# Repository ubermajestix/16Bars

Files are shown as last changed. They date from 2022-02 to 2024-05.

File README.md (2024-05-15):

# 16Bars


16barsPCB

16Bars is a utility module designed to display how many 
measures have elapsed on a seven segment display given a clock pulse. 
The module resets every 8 or 16 measures (bars) or when the reset button is pressed.

This is my first module design and I've made several simplifying design choices:
1. A 1U version would be much more convienient
2. Reset jack would be nice to play better with midi or modules that output reset
3. Midi support? Accept MIDI TRS input for start, stop, and reset?
4. LFO output with LFO reset, could use 1st bar, n/2 bars, and last bar to self patch musical phrased LFO
## Rev 3.2 Updates and Issues

## Rev 2.0 Updates and Issues
I was successfully able to get JLCPCB to manufacture and place a lot of SMD components as I don't have the time or gear to get into surface mount, win! 

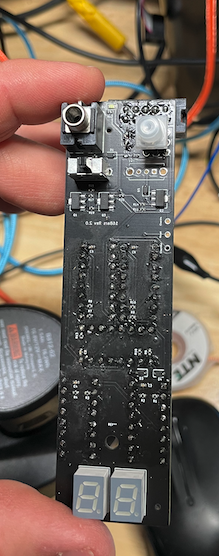
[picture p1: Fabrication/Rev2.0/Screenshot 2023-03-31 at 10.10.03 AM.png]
front of 2.0

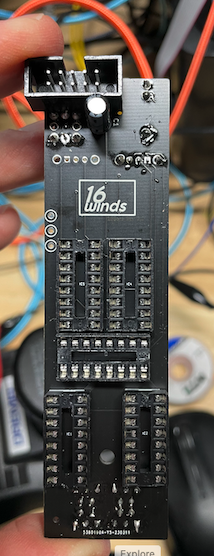
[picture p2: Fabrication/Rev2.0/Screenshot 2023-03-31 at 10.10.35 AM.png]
back of 2.0


I also breadboarded out and build test PCBS to validate significant portion of the Rev 2.0 design:
- Reset button uses a transistor to send a reset signal instead of directly sending +12v when pressed
- Two transistors to normalize a wide variety of incoming clock signal voltages and send +12v pulses to trigger the three counter ICs and blink the led in the reset button 
- 8 bar reset logic confirmed, 16 bar reset logic didn't work because I was rushing to get Rev 2.0 board to production.
- Built a switch test PCB. I ordered 4 different switches and after getting incorrect footprints for the seven segment leds from Mouser I didn't trust the switch footprints. I also wanted to validate the switch weight, height, footprint size tradeoffs, validate the switches are in-fact on-on SPDT, and ensure the switches are too able to be flipped by accident when patching as they control the reset logic and time signature (4/4 and 8/4). 

Issues
- The [surface mount transistors](https://www.lcsc.com/product-detail/Bipolar-Transistors-BJT_Jiangsu-Changjing-Electronics-Technology-Co-Ltd-C9634_C9634.html) do not work as intended. I am considering replacing them with through-hole NPN's I'm using on the breadboard to validate it's either a component problem or PCB routing problem. 

# Panel Design
Panel design ideas, PCB, and logo are in Panel/. I'm aiming for a wind theme throughout the design and naming.

Rev 2.0 panel design is coming along:

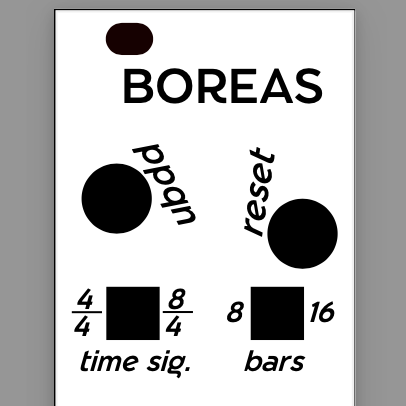
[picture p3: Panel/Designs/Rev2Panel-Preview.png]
panel preview


# LED Sheild Practice aka Clock Blink
The design and fabrication process can be intimidating for a beginner. What I've learned from
software development is to start easy and get something small all the way to production before tackling bigger
projects. 

I followed [Contextual Electronic's _Getting To Blinky 5.0](https://www.youtube.com/watch?v=BVhWh3AsXQs)_ to learn
KiCAD schematic design, PCB layout and design, and fabrication on a simple circuit.

I wanted to use a keyed power header, know it worked by lighting up an LED, and take a clock pulse in through a jack to light up an led.

I fabricated the boards and got the power led to light up from my Eurorack case! The blinking feature isn't working and
I'm debugging it as of March 2022. 

# Practice Panel
I also wanted to practice making a panel. Again, to simplify, I wanted to get the mounting holes placed correctly with oval
holes like Intellijel 1U modules b/c my rails are never exactly aligned top to bottom. I was planning to make a control panel for the
the ClockBlink board but I figured why not make a blank 1U panel with some Fiverr artwork? 

The blank panels turned out great, I fabbed them with OshPark.com in purple (their default) and black (After Dark). The holes
line up and they were $7 and $12 shipped for three copies.

sheep1u

# License
[Attribution 4.0 International (CC BY 4.0)](https://creativecommons.org/licenses/by/4.0/)

Open-source-hardware-logo

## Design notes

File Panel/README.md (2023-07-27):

# 16 Bars Panel

## Inspiration
16Winds name was inspired by a joke my wife and I made years ago when
I was doing side work to pay for our honeymoon. I would start my side
gig at 5:30am, work until my real job started at 8:30am, work a full
day, hit the gym around 5:30pm, cook dinner, hang out, enjoy some music
hobby time, relax together, and maybe knock out a few todo items. Late
into the evening we would joke we were on our 16th wind, instead of just 
a second wind, to get everything done in a day. 

When I started thinking about making synth modules I thought the name was
fitting as our lives have only gotten more busy with kids and work. The
time I'm able to spend working on this has drastically reduced and I really
feel like I'm on a 16th wind to get the energy to figure out electronics,
pcb design, panel design, manufacturing, part selection, branding and everything
else.

So 16Winds, how about naming the modules after the names given to the compass winds
(Borreas, Zephyrus, etc) thoughout antiquity, or maybe use the names of local winds (chinook, mistral, etc). 

## How To Get Artwork On The Panel
1. Design in InkScape
4. Use Svg2Shenzhen to setup layers
6. Resize artwork and place in layers (Svg2Shenzhen resizes the artboard, maybe I'm doing something wrong?)
7. Export to Kicad in a Footprints/ directory local to the project
8. Add local Footprints/ as a "Project Specific Library" in KiCad's Footprint Library Manager
9. Place footprints from new library.

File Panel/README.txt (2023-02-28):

# 16 Bars Panel

## Inspiration
16winds name was inspired by a joke my wife and I made years ago when
I was doing side work to pay for our honeymoon. I would start my side
gig at 5:30am, work until my real job started at 8:30am, work a full
day, hit the gym around 5:30pm, cook dinner, hang out, enjoy some music
hobby time, relax together, and maybe knock out a few todo items. Late
into the evening we would joke we were on our 16th wind, instead of just 
a second wind, to get everything done we wanted to in a day. 

When I started thinking about making synth modules I thought the name was
fitting as our lives have only gotten more busy with kids and work. The
time I'm able to spend working on this has drastically reduced and I really
feel like I'm on a 16th wind to get the energy need to figure out electronics,
pcb design, panel design, manufacturing, part selection, branding and everything
else.

So 16 winds, how about naming the modules after the names given to the compass winds
(Borreas, Zephyrus, etc) thoughout antiquity, or maybe use the names of local winds (chinook, mistral, etc). 

## How To Get Artwork On The Panel
1. Design in AffintyDesign
2. Export to SVG
3. Import to InkScape
4. Use Svg2Shenzhen to setup layers
6. Resize artwork and place in layers (Svg2Shenzhen resizes the artboard, maybe I'm doing something wrong?)
7. Export to Kicad in a Footprints/ directory local to the project
8. Add local Footprints/ as a "Project Specific Library" in KiCad's Footprint Library Manager
9. Place footprints from new library.

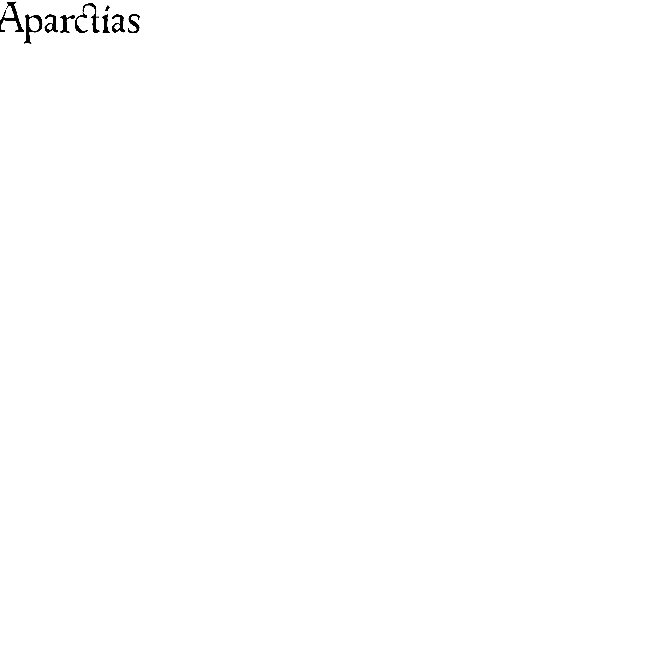
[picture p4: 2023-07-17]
Panel/Footprints/.svg2shenzhen-cache/images/F.SilkS_g187.png

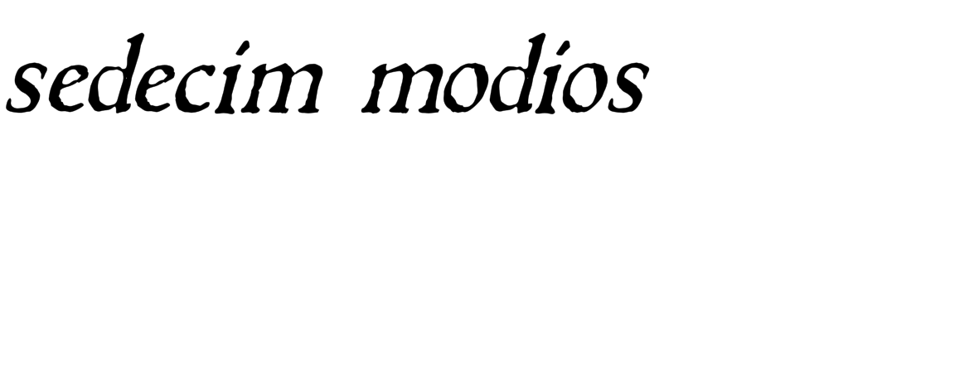
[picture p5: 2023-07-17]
Panel/Footprints/.svg2shenzhen-cache/images/F.Cu_g155.png

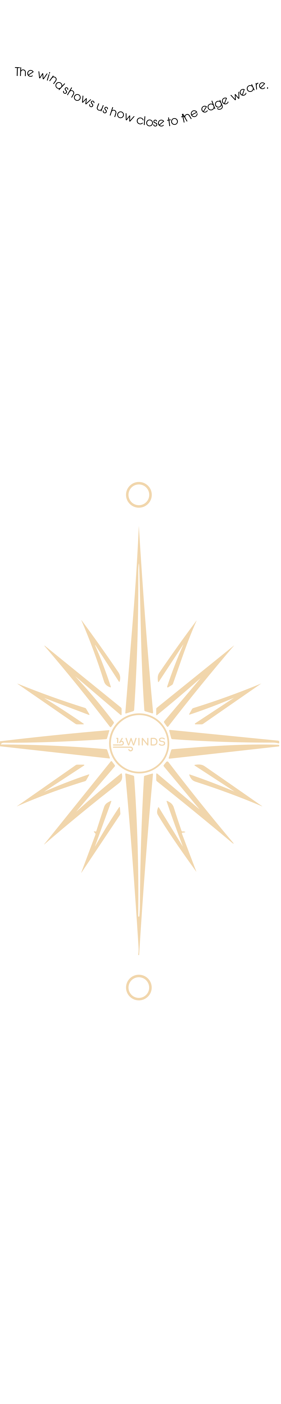
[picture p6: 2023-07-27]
Panel/Footprints/.svg2shenzhen-cache/images/B.Cu_g4975.png

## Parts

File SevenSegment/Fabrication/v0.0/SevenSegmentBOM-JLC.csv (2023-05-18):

Id | Designator | Footprint | Comment | LCSC Part Number
3 | R4,R3,R2,R1 | R_0402_1005Metric | 10K | C25744
5 | C2,C1 | C_0402_1005Metric | 100nf | C1525

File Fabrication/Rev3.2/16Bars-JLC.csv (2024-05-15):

Comment | Designator | Footprint | LCSC Part Number
330pf Unpolarized capacitor, small symbol | C11, | Capacitor_SMD:C_0402_1005Metric | C13533
LED Light emitting diode | D2, | LED_SMD:LED_0603_1608Metric | C2290
1N5819WS Diode | D5, D6, D7, D8, D9, | Diode_SMD:D_SOD-323 | C191023
470 Resistor | R1, R2, R3, R5, | Resistor_SMD:R_0402_1005Metric | C25117
1K Resistor | R4, R6, R7, R15, | Resistor_SMD:R_0402_1005Metric | C4410
10K Resistor | R12, | Resistor_SMD:R_0402_1005Metric | C4109

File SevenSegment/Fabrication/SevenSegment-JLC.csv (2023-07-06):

Comment | Designator | Footprint | LCSC Part Number
100nf Unpolarized capacitor | C1, C2, | Capacitor_SMD:C_0402_1005Metric | C1525
10K Resistor | R1, R2, R3, R4, | Resistor_SMD:R_0402_1005Metric | C25744

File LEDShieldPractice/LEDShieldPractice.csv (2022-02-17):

Source: | C:\Users\Tyler\Documents\KiCad\16Bars\LEDShieldPractice\LEDShieldPractice.kicad_sch
Date: | 2/15/2022 3:33:57 PM
Tool: | Eeschema (6.0.0)
Generator: | C:\Program Files\KiCad\6.0\bin\scripting\plugins/bom_csv_grouped_by_value.py
Component Count: | 11
Individual Components:
Item | Qty | Reference(s) | Value | LibPart | Footprint | Datasheet
 |  | C1 | 47uf | Device:C_Polarized_Small_US | Capacitor_THT:CP_Radial_D6.3mm_P2.50mm | ~
 |  | D1 | 1N4148 | Device:D | Diode_THT:D_A-405_P7.62mm_Horizontal | ~
 |  | D2 | LED | Device:LED | LED_THT:LED_D3.0mm | ~
 |  | DPWR1 | LED | Device:LED | LED_THT:LED_D3.0mm | ~
 |  | J1 | Conn_02x05_Odd_Even | Connector_Generic:Conn_02x05_Odd_Even | Connector_PinHeader_2.54mm:PinHeader_2x05_P2.54mm_Vertical | ~
 |  | J2 | CLOCK_IN | Connector:AudioJack2 | Connector_Audio:Jack_3.5mm_QingPu_WQP-PJ398SM_Vertical_CircularHoles | ~
 |  | Q1 | 2N3904 | Transistor_BJT:2N3904 | Package_TO_SOT_THT:TO-92_Inline | https://www.onsemi.com/pub/Collateral/2N3903-D.PDF
 |  | R1 | 500 | Device:R | Resistor_THT:R_Axial_DIN0204_L3.6mm_D1.6mm_P5.08mm_Horizontal | ~
 |  | R2 | 500 | Device:R | Resistor_THT:R_Axial_DIN0204_L3.6mm_D1.6mm_P5.08mm_Horizontal | ~
 |  | R3 | 47K | Device:R | Resistor_THT:R_Axial_DIN0204_L3.6mm_D1.6mm_P5.08mm_Horizontal | ~
 |  | R4 | 10k | Device:R | Resistor_THT:R_Axial_DIN0204_L3.6mm_D1.6mm_P5.08mm_Horizontal | ~
Collated Components:
Item | Qty | Reference(s) | Value | LibPart | Footprint | Datasheet
1 | 1 | C1 | 47uf | Device:C_Polarized_Small_US | Capacitor_THT:CP_Radial_D6.3mm_P2.50mm | ~
2 | 1 | D1 | 1N4148 | Device:D | Diode_THT:D_A-405_P7.62mm_Horizontal | ~
3 | 2 | D2, DPWR1 | LED | Device:LED | LED_THT:LED_D3.0mm | ~
4 | 1 | J1 | Conn_02x05_Odd_Even | Connector_Generic:Conn_02x05_Odd_Even | Connector_PinHeader_2.54mm:PinHeader_2x05_P2.54mm_Vertical | ~
5 | 1 | J2 | CLOCK_IN | Connector:AudioJack2 | Connector_Audio:Jack_3.5mm_QingPu_WQP-PJ398SM_Vertical_CircularHoles | ~
6 | 1 | Q1 | 2N3904 | Transistor_BJT:2N3904 | Package_TO_SOT_THT:TO-92_Inline | https://www.onsemi.com/pub/Collateral/2N3903-D.PDF
7 | 2 | R1, R2 | 500 | Device:R | Resistor_THT:R_Axial_DIN0204_L3.6mm_D1.6mm_P5.08mm_Horizontal | ~
8 | 1 | R3 | 47K | Device:R | Resistor_THT:R_Axial_DIN0204_L3.6mm_D1.6mm_P5.08mm_Horizontal | ~
9 | 1 | R4 | 10k | Device:R | Resistor_THT:R_Axial_DIN0204_L3.6mm_D1.6mm_P5.08mm_Horizontal | ~

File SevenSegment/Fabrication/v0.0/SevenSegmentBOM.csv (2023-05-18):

Id | Designator | Package | Quantity | Designation | Supplier and ref
1 | DS-TENS1,DS-ONES1 | TDSR0760 | 2 | TDSR0760
2 | IC2,IC1 | DIP794W53P254L1930H508Q16N | 2 | CD4033BE
3 | R4,R3,R2,R1 | R_0402_1005Metric | 4 | 10K
4 | J1 | Pins_1x04_2.54mm_TH_SWD | 1 | Conn_01x04
5 | C2,C1 | C_0402_1005Metric | 2 | 100nf

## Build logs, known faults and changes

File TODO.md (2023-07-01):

# TODO
6. Reduce to 4HP.
7. Is SevenSegment more stable with shift registers controlled by Arduino? 4033 docs say they are easily inteferred with, and they seem a little wonky, maybe it's my soldering, but they don't always work. 
8. Some pins on Nano are non-functional or a bit wonky
* D12 output (firstbar jack) very low voltage
* D6 input (8/16 bars switch) non functional, jumpered to A4
9. Probably need to move to Schmitt trigger, does JLC have SMD? This would help condition outputs to correct voltage and protect Nano from modular craziness. 
10. SeverSegment - assemble with ICs on top for more space
11. Use 2x 01x02 connectors for seven segment to make it more mechanically stable.
12. Change name from Boreas to Aparctias. Boreas wasn't a nice god of wind.

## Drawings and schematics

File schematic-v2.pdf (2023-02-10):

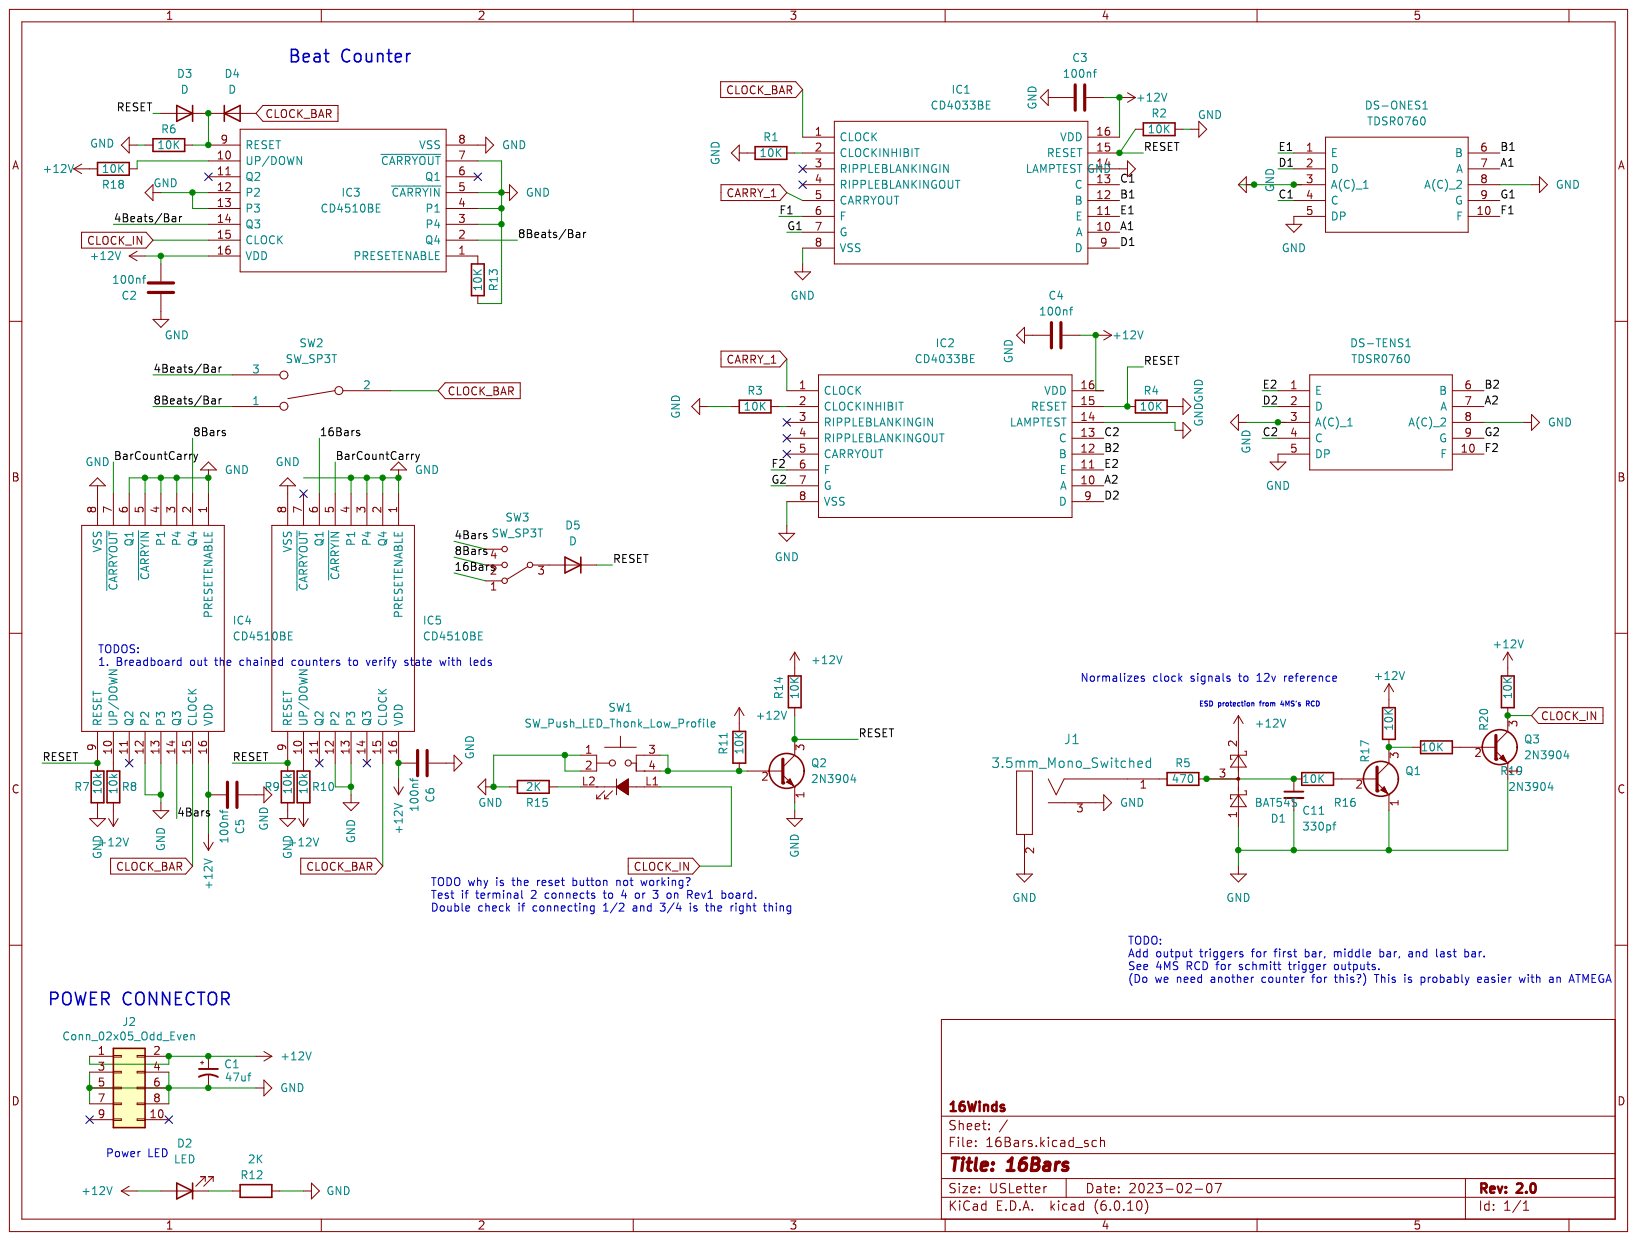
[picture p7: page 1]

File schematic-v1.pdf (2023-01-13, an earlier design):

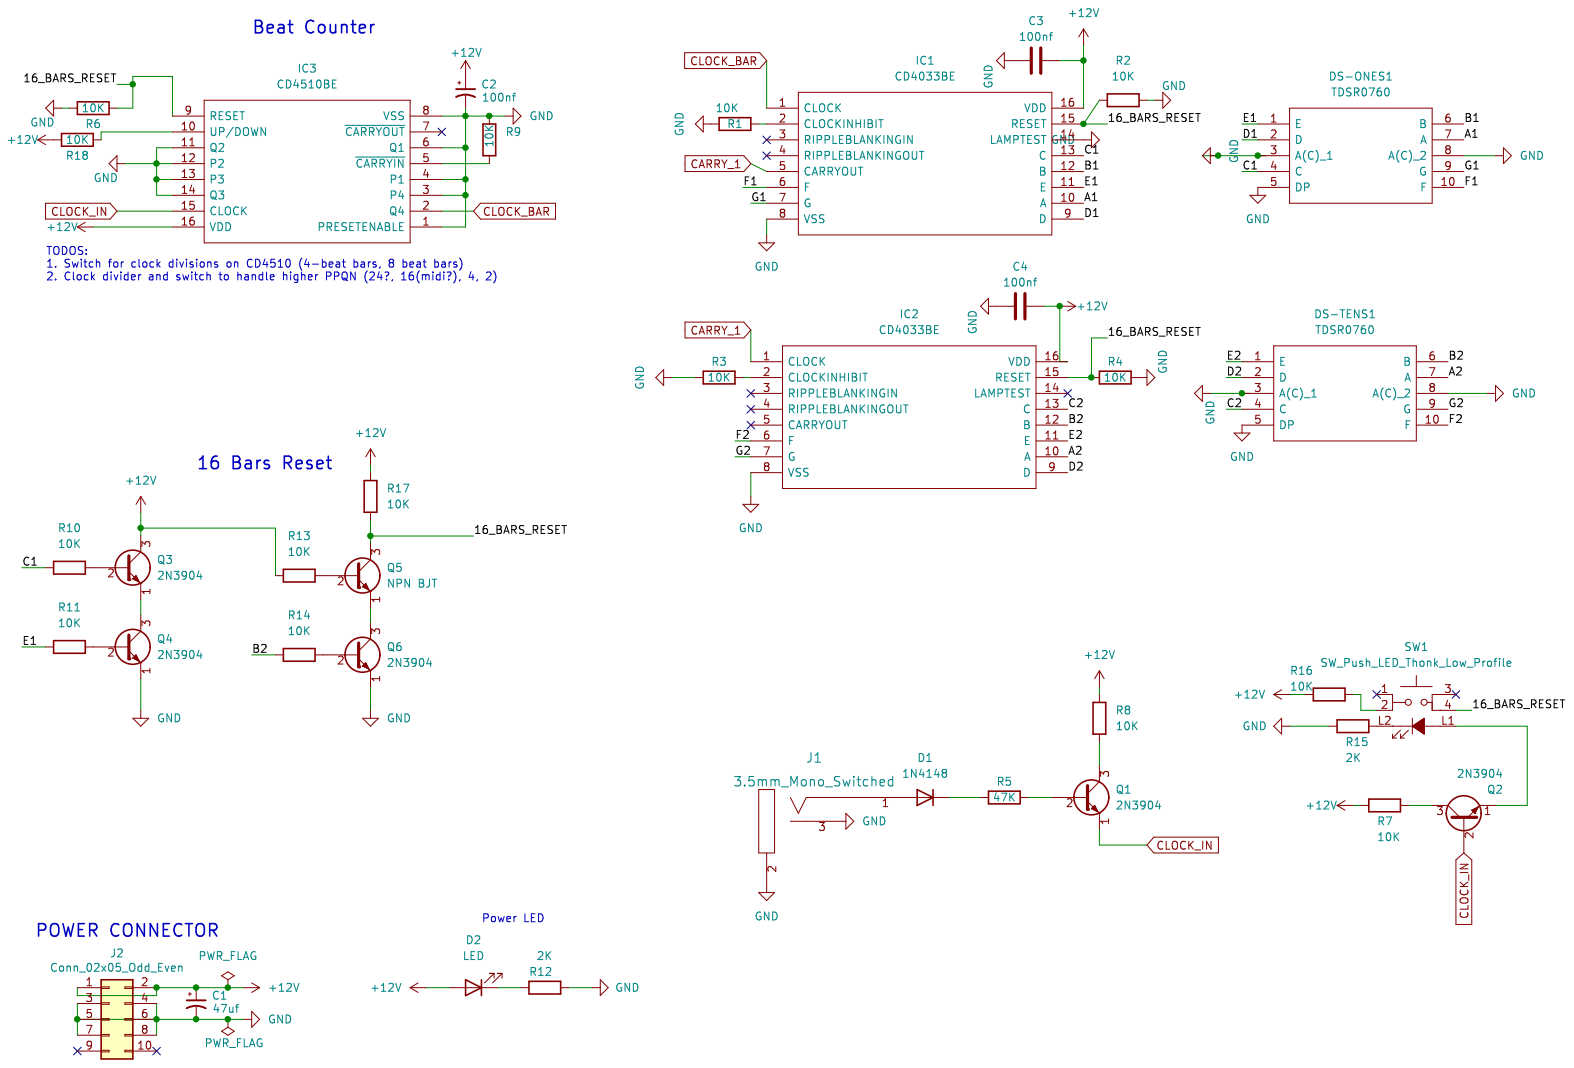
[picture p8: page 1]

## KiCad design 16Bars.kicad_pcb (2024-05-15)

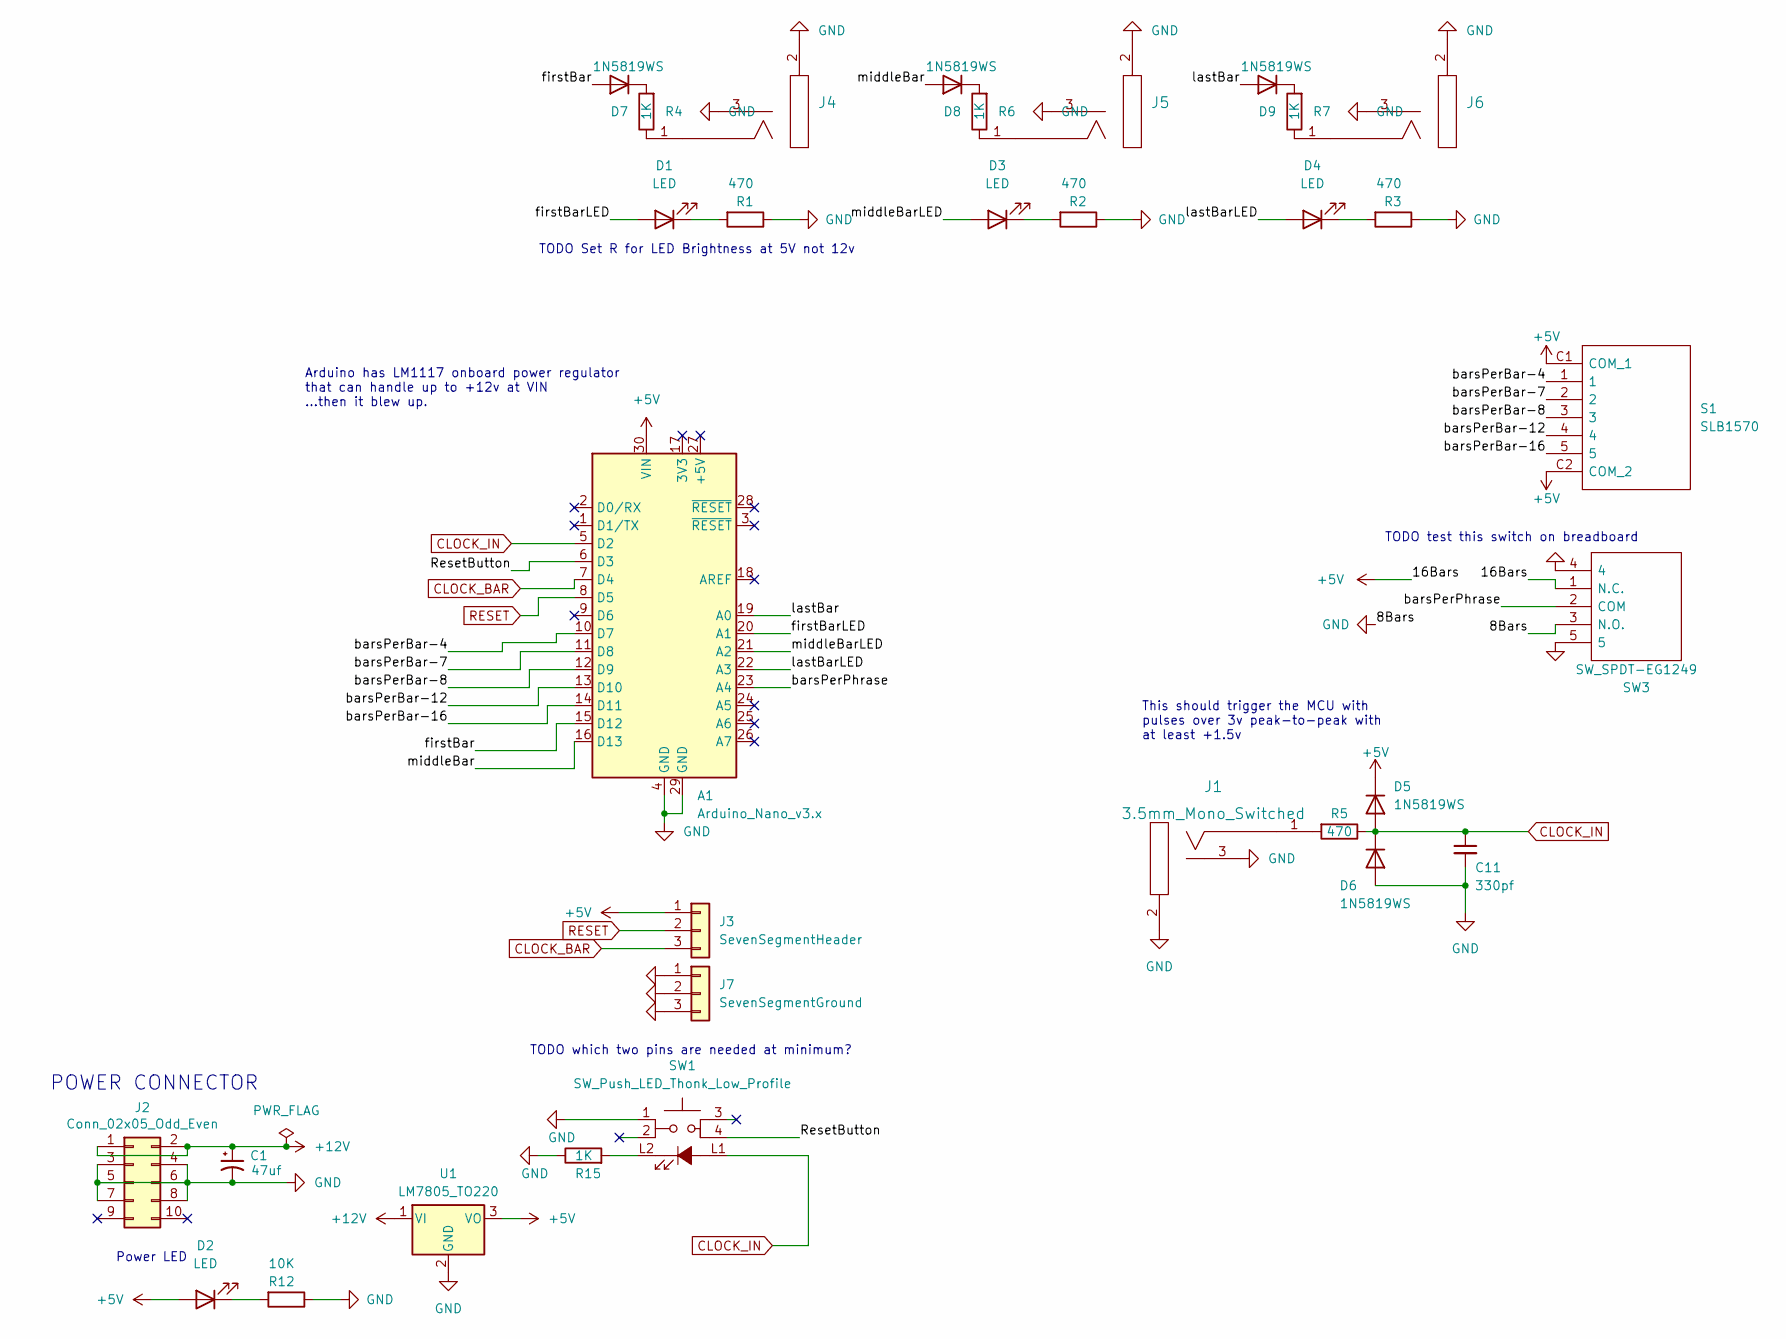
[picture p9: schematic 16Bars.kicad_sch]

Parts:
A1: Arduino_Nano_v3.x; Arduino_Nano
C1: 47uf; CP_Radial_D5.0mm_P2.00mm
C11: 330pf; C_0402_1005Metric; Manufacturer_Part_Number C13533; LCSC C13533
D1, D3, D4: LED; LED_D3.0mm
D2: LED; LED_0603_1608Metric; Manufacturer_Part_Number C2290; LCSC C2290
D5, D6, D7, D8, D9: 1N5819WS; D_SOD-323; Manufacturer_Part_Number C191023; LCSC C191023
J1, J4, J5, J6: 3.5mm_Mono_Switched; EighthInch_PJ398SM; Part Number WQP-WQP518MA
J2: Conn_02x05_Odd_Even; PinHeader_2x05_P2.54mm_Vertical
J3: SevenSegmentHeader; Pins_1x03_2.54mm_TH_AudioInsRGndL; Part Number 1-0301FBV0T
J7: SevenSegmentGround; Pins_1x03_2.54mm_TH_AudioInsRGndL; Part Number 1-0301FBV0T
R1, R2, R3: 470; R_0402_1005Metric; Manufacturer_Part_Number C4109; LCSC C25117
R4, R6, R7, R15: 1K; R_0402_1005Metric; Manufacturer_Part_Number C4109; LCSC C4410
R5: 470; R_0402_1005Metric; Manufacturer_Part_Number C25792; LCSC C25117
R12: 10K; R_0402_1005Metric; Manufacturer_Part_Number C4109; LCSC C4109
S1: SLB1570; Mouser Part Number 642-SLB1570
SW1: SW_Push_LED_Thonk_Low_Profile; ThonkLowProfileButton
SW3: SW_SPDT-EG1249; EG1249; Mouser Part Number 612-EG1249
U1: LM7805_TO220; TO-220-3_Vertical

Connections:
+5V: A1.30 (VIN), D2.2 (A), D5.1 (K), J3.1, S1.C1 (COM_1), S1.C2 (COM_2), SW3.1 (N.C.), U1.3 (VO)
+12V: C1.1, J2.1, J2.2, U1.1 (VI)
/ResetButton: A1.6 (D3), SW1.4
/barsPerBar-4: A1.10 (D7), S1.1
/barsPerBar-7: A1.11 (D8), S1.2
/barsPerBar-8: A1.12 (D9), S1.3
/barsPerBar-12: A1.13 (D10), S1.4
/barsPerBar-16: A1.14 (D11), S1.5
/barsPerPhrase: A1.23 (A4), SW3.2 (COM)
/firstBar: A1.15 (D12), D7.2 (A)
/firstBarLED: A1.20 (A1), D1.2 (A)
/lastBar: A1.19 (A0), D9.2 (A)
/lastBarLED: A1.22 (A3), D4.2 (A)
/middleBar: A1.16 (D13), D8.2 (A)
/middleBarLED: A1.21 (A2), D3.2 (A)
CLOCK_BAR: A1.7 (D4), J3.3
CLOCK_IN: A1.5 (D2), C11.1, D5.2 (A), D6.1 (K), R5.1, SW1.L1
GND: A1.4 (GND), A1.29 (GND), C1.2, C11.2, D6.2 (A), J1.2 (SHEILD), J1.3 (SW), J2.3, J2.4, J2.5, J2.6, J2.7, J2.8, J4.2 (SHEILD), J4.3 (SW), J5.2 (SHEILD), J5.3 (SW), J6.2 (SHEILD), J6.3 (SW), J7.1, J7.2, J7.3, R1.1, R2.1, R3.1, R12.1, R15.1, SW1.1, SW3.3 (N.O.), SW3.4, SW3.5, U1.2 (GND)
unnamed: D1.1 (K), R1.2
unnamed: D2.1 (K), R12.2
unnamed: D3.1 (K), R2.2
unnamed: D4.1 (K), R3.2
unnamed: D7.1 (K), R4.2
unnamed: D8.1 (K), R6.2
unnamed: D9.1 (K), R7.2
unnamed: J1.1 (SIG), R5.2
unnamed: J4.1 (SIG), R4.1
unnamed: J5.1 (SIG), R6.1
unnamed: J6.1 (SIG), R7.1
unnamed: R15.2, SW1.L2
RESET: A1.8 (D5), J3.2

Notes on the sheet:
POWER CONNECTOR
Arduino has LM1117 onboard power regulator that can handle up to +12v at VIN ...then it blew up.
Power LED
TODO test this switch on breadboard
TODO which two pins are needed at minimum?
TODO Set R for LED Brightness at 5V not 12v
This should trigger the MCU with pulses over 3v peak-to-peak with at least +1.5v

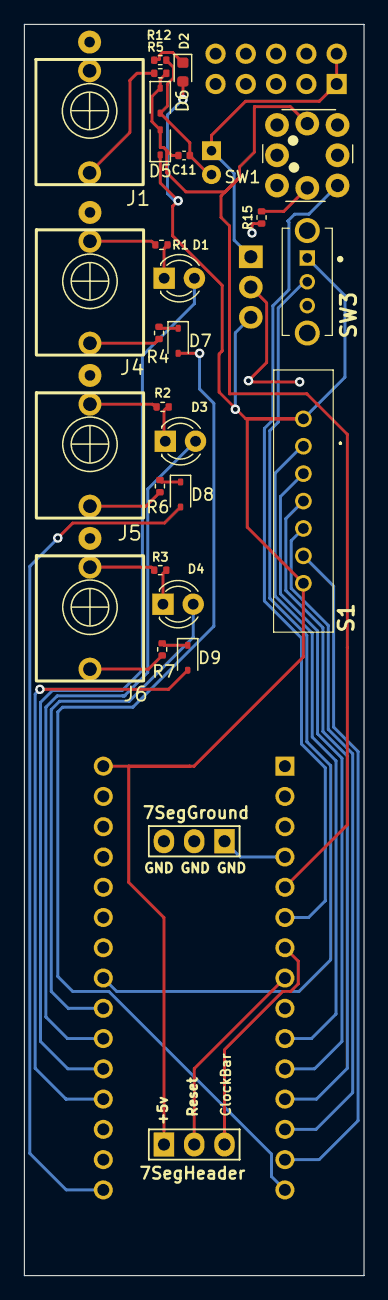
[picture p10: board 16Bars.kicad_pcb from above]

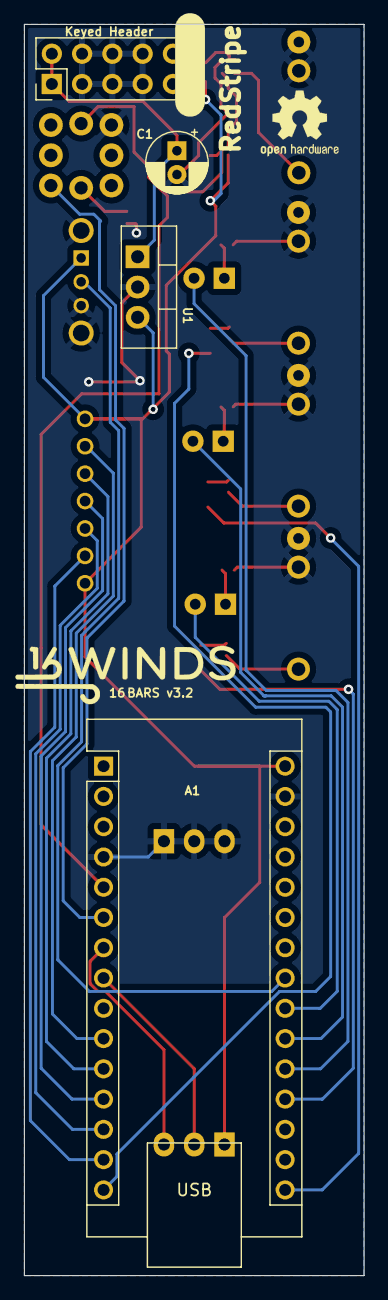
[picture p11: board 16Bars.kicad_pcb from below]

Board: 2 copper layers, 28.5 x 105.0 mm, 33 parts (5 on the bottom side), 31 nets.

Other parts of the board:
Ref**: Val**; 16WindsLogoJuly2023-12mm

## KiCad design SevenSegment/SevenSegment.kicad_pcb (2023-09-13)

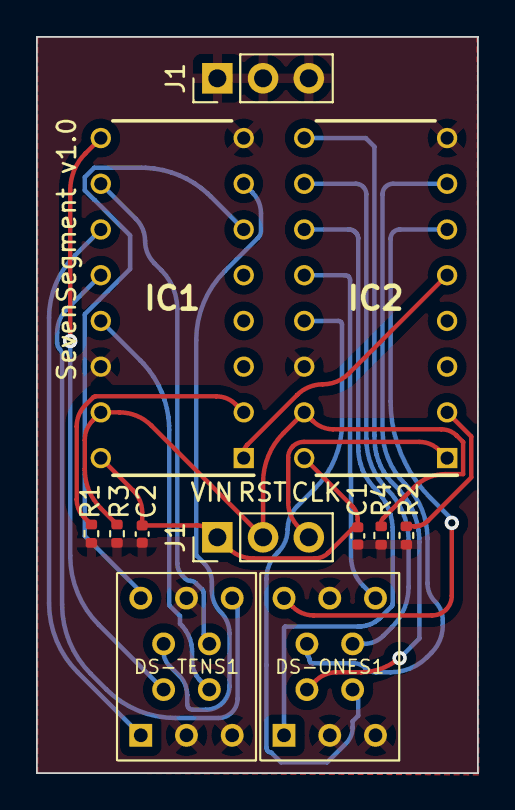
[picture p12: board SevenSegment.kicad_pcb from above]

Board: 2 copper layers, 24.5 x 40.9 mm, 12 parts (0 on the bottom side), 21 nets.

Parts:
C1, C2: 100nf; C_0402_1005Metric
DS-ONES1: TDSR0760
DS-TENS1: TDSR0760
IC1, IC2: CD4033BE; DIP794W53P254L1930H508Q16N
J1, J1#2: Conn_01x04; PinHeader_1x03_P2.54mm_Vertical
R1, R2, R3, R4: 10K; R_0402_1005Metric

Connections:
+12V: C1.2, C2.2, IC1.16 (VDD), IC2.16 (VDD), J1.1
/A1: DS-ONES1.7 (A), IC2.10 (A)
/A2: DS-TENS1.7 (A), IC1.10 (A)
/B1: DS-ONES1.6 (B), IC2.12 (B)
/B2: DS-TENS1.6 (B), IC1.12 (B)
/C1: DS-ONES1.4 (C), IC2.13 (C)
/C2: DS-TENS1.4 (C), IC1.13 (C)
/D1: DS-ONES1.2 (D), IC2.9 (D)
/D2: DS-TENS1.2 (D), IC1.9 (D)
/E1: DS-ONES1.1 (E), IC2.11 (E)
/E2: DS-TENS1.1 (E), IC1.11 (E)
/F1: DS-ONES1.10 (F), IC2.6 (F)
/F2: DS-TENS1.10 (F), IC1.6 (F)
/G1: DS-ONES1.9 (G), IC2.7 (G)
/G2: DS-TENS1.9 (G), IC1.7 (G)
/RESET: IC1.15 (RESET), IC2.15 (RESET), J1.2, R3.2, R4.2
CARRY_1: IC1.1 (CLOCK), IC2.5 (CARRYOUT)
CLOCK_BAR: IC2.1 (CLOCK), J1.3
GND: C1.1, C2.1, DS-ONES1.3 (A(C)_1), DS-ONES1.5 (DP), DS-ONES1.8 (A(C)_2), DS-TENS1.3 (A(C)_1), DS-TENS1.5 (DP), DS-TENS1.8 (A(C)_2), IC1.8 (VSS), IC1.14 (LAMPTEST), IC2.8 (VSS), IC2.14 (LAMPTEST), J1#2.1, J1#2.2, J1#2.3, R1.2, R2.2, R3.1, R4.1
unnamed: IC1.2 (CLOCKINHIBIT), R1.1
unnamed: IC2.2 (CLOCKINHIBIT), R2.1

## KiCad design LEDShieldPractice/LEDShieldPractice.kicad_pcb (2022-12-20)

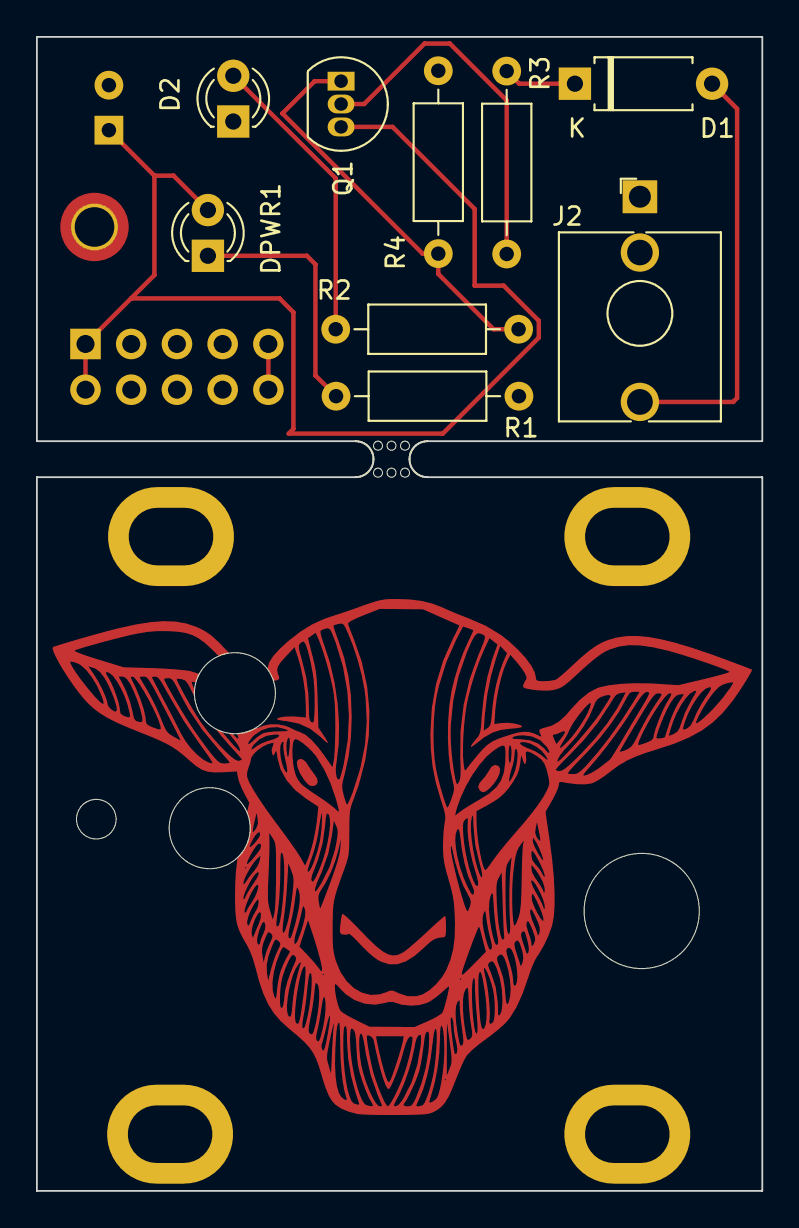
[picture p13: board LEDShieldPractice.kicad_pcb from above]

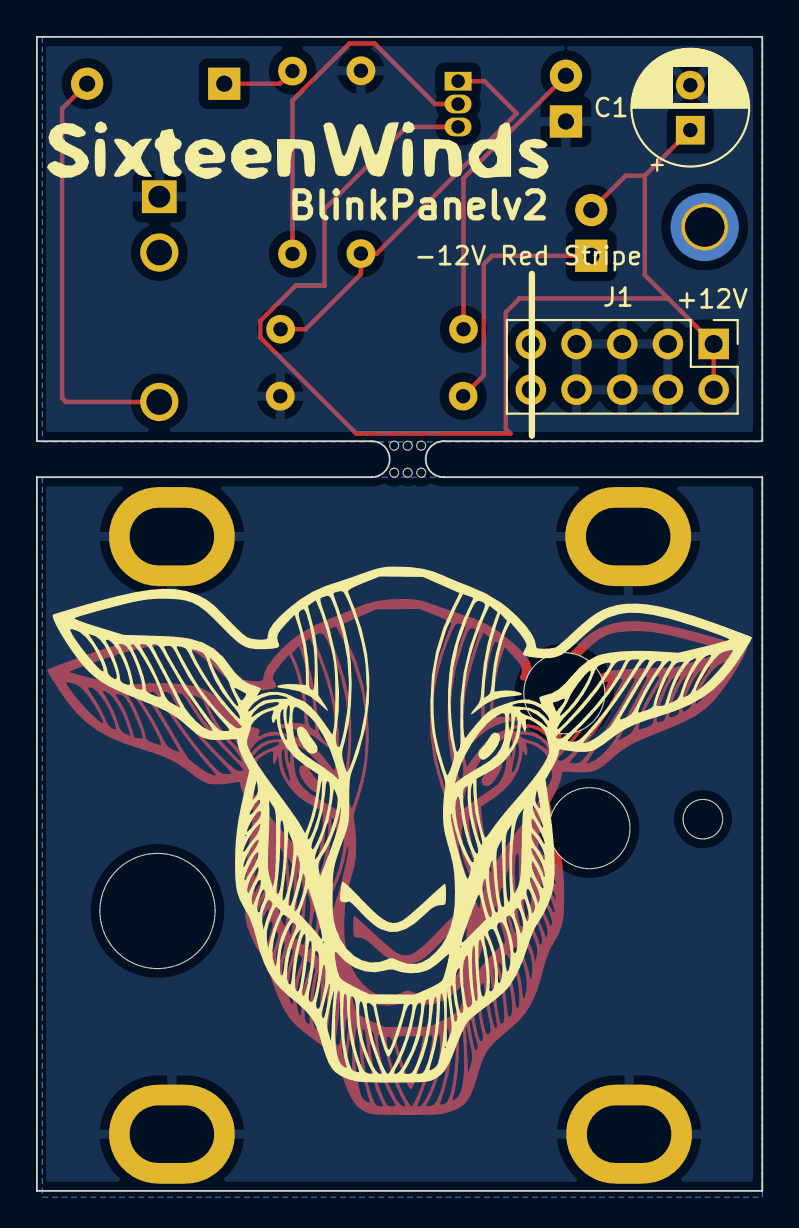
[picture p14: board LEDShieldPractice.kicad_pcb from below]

Board: 2 copper layers, 40.3 x 64.1 mm, 16 parts (2 on the bottom side), 9 nets.

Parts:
C1: 47uf; CP_Radial_D6.3mm_P2.50mm
D1: 1N4148; D_A-405_P7.62mm_Horizontal
D2: LED; LED_D3.0mm
DPWR1: LED; LED_D3.0mm
H1, H2, H3, H4: MountingHole_Pad; MountingHole_3.2mm_M3_IntellijelOval_Pad
J1: Conn_02x05_Odd_Even; PinHeader_2x05_P2.54mm_Vertical
J2: CLOCK_IN; Jack_3.5mm_QingPu_WQP-PJ398SM_Vertical_CircularHoles
Q1: 2N3904; TO-92_Inline
R1, R2: 2000; R_Axial_DIN0207_L6.3mm_D2.5mm_P10.16mm_Horizontal
R3: 47K; R_Axial_DIN0207_L6.3mm_D2.5mm_P10.16mm_Horizontal
R4: 10k; R_Axial_DIN0207_L6.3mm_D2.5mm_P10.16mm_Horizontal
mouse-bite-2mm-slot: VAL**; mouse-bite-2mm-slot

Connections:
+12V: C1.1, DPWR1.2 (A), J1.1, J1.2, Q1.3 (C)
-12V: J1.9, J1.10
CLOCK: Q1.1 (E), R2.1, R4.1
GND: C1.2, D2.1 (K), H1.1, H2.1, H3.1, H4.1, J1.3, J1.4, J1.5, J1.6, J1.7, J1.8, J2.S, R1.2, R4.2
unnamed: D1.1 (K), R3.2
unnamed: D1.2 (A), J2.T
unnamed: D2.2 (A), R2.2
unnamed: DPWR1.1 (K), R1.1
unnamed: Q1.2 (B), R3.1

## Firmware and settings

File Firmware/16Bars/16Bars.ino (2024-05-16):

#include "src/debug.h"
#include "src/UberPin/UberPin.h"

// TIP: for knockoff Arduino Nanos you may need a CH340 driver from Jan 2019 or
// earlier to upload this sketch or communicate with the board via USB.
// The CH340 driver can be found at Sparkfun: 
// https://learn.sparkfun.com/tutorials/how-to-install-ch340-drivers/all

const byte clockPinNum = 2;
const byte resetButtonPinNum = 3;
const byte clockBarPinNum = 4;
const byte resetOutPinNum = 5;
const byte barsPerPhrasePinNum = A4;
const byte beatsPerBarPins[5] = {7, 8, 9, 10, 11};
const byte firstBarOutPin = 12;
const byte middleBarOutPin = 13;
const byte firstBarLEDPin = A1;
// FIXME PCB layout put LEDs in the wrong spots, swapping pins to fix it.
const byte middleBarLEDPin = A2;
// const byte middleBarLEDPin = A3;
const byte lastBarOutPin = A0;
// const byte lastBarLEDPin = A2;
const byte lastBarLEDPin = A3;
const byte ledPins[3] = {firstBarLEDPin, middleBarLEDPin, lastBarLEDPin};

const byte beatsPerBarValues[5] = {4, 7, 8, 12, 16};
const byte barsPerPhraseValues[2] = {8,16}; 

// TESTING Internal clock settings
volatile unsigned long enterInternalClockModeTime = 0; // Enter this mode if reset button pressed for 3 seconds within 10 seconds of startup
volatile byte internalClock = 0; // Testing mode active when 1
const unsigned long internalBPM = 345; // 174 bpm 1/4 note is 345ms
volatile unsigned long lastClockTime = 0; // For auto-reset and internal clock feature. // TODO use "Last" output clock to self patch for testing?


UberPin clockPin(clockPinNum);
UberPin resetButtonPin(resetButtonPinNum, 5);
UberPin clockBarPin(clockBarPinNum);
UberPin resetOutPin(resetOutPinNum);

volatile byte beatCounter = 0; // Counter for the clock pulses
volatile byte barCounter = 0;  // Counter for bars
// Set default values for barPerPhrase and beatsPerBar but in setup() we'll select values off the slider inputs.
volatile byte barsPerPhrase = barsPerPhraseValues[1]; // Default is 16 bars because, uh, that's the name of the project.
volatile byte beatsPerBar= beatsPerBarValues[0]; // Default is 4. Can be set to 4, 7, 8, 12, 16 with switch 
volatile byte resetButtonPressed = 0;
volatile bool clockBarState = LOW; // Led State, initially set to LOW
volatile bool resetPhrase = LOW;
// TODO add separate extneral outputs for clockbar (firstbar == reset)
// TODO add another out 1 measure before middle bar?
volatile bool firstBar = LOW;
volatile bool middleBar = LOW;
volatile bool lastBar = LOW;

void setup(){
  pinMode(clockPinNum, INPUT);
  pinMode(barsPerPhrasePinNum, INPUT_PULLUP);
  pinMode(resetButtonPinNum, INPUT_PULLUP);
  // Set up the beatsPerBar 5 position switch pins as inputs
  for (int i = 0; i < 5; i++) {
    pinMode(beatsPerBarPins[i], INPUT);
  }
  pinMode(clockBarPinNum, OUTPUT);
  pinMode(resetOutPinNum, OUTPUT);
  pinMode(firstBarOutPin, OUTPUT);
  pinMode(firstBarLEDPin, OUTPUT);
  pinMode(middleBarOutPin, OUTPUT);
  pinMode(middleBarLEDPin, OUTPUT);
  pinMode(lastBarOutPin, OUTPUT);
  pinMode(lastBarLEDPin, OUTPUT);
  Serial.begin(9600);
  flashLedStartup();
  changeBeatsAndBars();

}

void flashLedStartup(){
  resetOutPin.write(HIGH);
  delay(10);
  resetOutPin.write(LOW);

  // Count from 0 to 16 then pause on 16 for 1 second
  for (int i = 0; i < 16; i++)
  {
    clockBarPin.write(HIGH);
    delay(50);
    if(i == 15){
      delay(650);
    }
    clockBarPin.write(LOW);
    delay(50);
  }

  // Set Counter to "01" instead of "00" on startup before LEDs flash
  resetOutPin.write(HIGH);
  resetOutPin.write(LOW);
  clockBarPin.write(HIGH); 
  clockBarPin.write(LOW);

  // Flash the leds three times
  for (int i = 0; i < 3; i++)
  {
    flashLEDs();
  }
}

void flashLEDs(){
 for (int i = 0; i < 3; i++)
  {
    digitalWrite(ledPins[i], HIGH);
    delay(50);
    digitalWrite(ledPins[i], LOW);
  }
 for (int i = 2; i >= 0; i--)
  {
    digitalWrite(ledPins[i], HIGH);
    delay(50);
    digitalWrite(ledPins[i], LOW);
  }
}
void flashLEDSync(){
  digitalWrite(ledPins[0], LOW);
  digitalWrite(ledPins[1], LOW);
  digitalWrite(ledPins[2], LOW); 
  digitalWrite(ledPins[0], HIGH);
  digitalWrite(ledPins[1], HIGH);
  digitalWrite(ledPins[2], HIGH);
  delay(150);
  digitalWrite(ledPins[0], LOW);
  digitalWrite(ledPins[1], LOW);
  digitalWrite(ledPins[2], LOW); 
}

void loop(){
  // Enter internal clock mode if reset button pressed and held for 3 seconds within 10 seconds of startup
  if(millis() <= 10000 && internalClock != 1 && enterInternalClockModeTime != 0 && millis() - enterInternalClockModeTime >= 3000){
    debugln("----Internal Clock ---");
    for (int i = 0; i < 3; i++){flashLEDSync(); delay(150);}
    internalClock = 1;
  }
  // Auto reset the counters if we haven't seen a clock signal for 4 seconds. 
  if(lastClockTime != 0 && millis() - lastClockTime >= 4000){
    debugln("----AUTO RESET ------");
    resetCounters();
  }
  
  if (resetButtonPin.changed()){
    if (resetButtonPin.direction == 1){
      debugln("---Reset Release---");
      resetOutPin.write(LOW);
      resetButtonPressed = 0;
    }
    else {
      debugln("----Reset Press---");
      // If reset button is long pressed for 3 seconds within 10 seconds post-setup, then enter test mode.
      enterInternalClockModeTime = millis();
      // When reset button is pressed we reset the counters, 
      resetCounters();
      resetButtonPressed = 1;
    }
  }
  // TESTING MODE: if internal clock is active don't read incoming clock 
  // and increment the counter based on internalBPM
  if (internalClock == 1){
    unsigned long internalClockTime = millis();
    if(internalClockTime - lastClockTime > internalBPM){
      if (!resetButtonPressed){
        incrementCounters();
      }
    }
  }
  // External clock input mode
  else{
    if (clockPin.changed() && clockPin.direction == 1){ 
      // if there's a clock and the resetbutton (pullup) is not pressed increment counter
      if (!resetButtonPressed){
        incrementCounters();
      }
    }
  }

}

void resetCounters(){
  debugln("------RESET------");
  // check if we need to change beats or bars and output a 
  // high reset signal to the CD4033 counters to reset the seven segment leds
  barCounter = 0;
  beatCounter = 0;
  firstBar = LOW;
  middleBar = LOW;
  lastBar = LOW;
  digitalWrite(firstBarOutPin, firstBar);
  digitalWrite(firstBarLEDPin, firstBar);
  digitalWrite(middleBarOutPin, middleBar);
  digitalWrite(middleBarLEDPin, middleBar);
  digitalWrite(lastBarOutPin, lastBar);
  digitalWrite(lastBarLEDPin, lastBar);
  changeBeatsAndBars();
  // Reset 4033's to "00"
  resetOutPin.write(HIGH);
  resetOutPin.write(LOW);
  // Increment 4033's to "01"
  clockBarPin.write(LOW); 
  clockBarPin.write(HIGH);
  clockBarPin.write(LOW);
}
// This function will be called whenever a rising edge is detected from the clock
void incrementCounters(){
  lastClockTime = millis();
  if(barCounter == 0){
    firstBar = HIGH;
  }
  clockBarPin.write(clockBarState);
  resetOutPin.write(resetPhrase); // sends reset to 4033
  // Incement 4033 counters to show "01" to count from 1 to barsPerPhrase instead of 0 to (barsPerPhrase - 1)
  if(resetPhrase == HIGH){
    resetOutPin.write(LOW);
    clockBarPin.write(LOW); 
    clockBarPin.write(HIGH);
    clockBarPin.write(LOW);
  }
  digitalWrite(firstBarOutPin, firstBar);
  digitalWrite(firstBarLEDPin, firstBar);
  digitalWrite(middleBarOutPin, middleBar);
  digitalWrite(middleBarLEDPin, middleBar);
  digitalWrite(lastBarOutPin, lastBar);
  digitalWrite(lastBarLEDPin, lastBar);

  
  // Reset output pins after writing any changes.
  // All these pins will output synchronously with the clock at the same 
  // length of the input clock pulse (~5 milliseconds).
  clockBarState = LOW;
  resetPhrase = LOW;
  firstBar = LOW; // TODO first bar and reseet are the same thing. Can we reset the 4033's, light up an led, and input to a schmitt trigger with one pin?
  middleBar = LOW;
  lastBar = LOW;
  
  beatCounter++;
  debug("beat ");
  debug(beatCounter);
  // End of measure, output HIGH clockbar on next clock signal
  if (beatCounter >= beatsPerBar){
    clockBarState = HIGH;
    barCounter++;
    beatCounter = 0;
  }
  // Check for first, middle, and last bar. 
  // TODO validate if this should happen AFTER incrementing barCounter.
  // firstBar is the same as reset, handled below.
 
  if(barCounter == barsPerPhrase/2){
    middleBar = HIGH;
  }
  if(barCounter == barsPerPhrase - 1){
    lastBar = HIGH;
  }
  // End of phrase: reset counters, check for beats/bar changes, and output HIGH reset on next clock
  if (barCounter >= barsPerPhrase){
    resetPhrase = HIGH;
    barCounter = 0;
    beatCounter = 0;
    changeBeatsAndBars();
  }
  debug(" reset: "); debug(resetPhrase);
  debug(" clockBar: "); debug(clockBarState); debug("/"); debug(barsPerPhrase);
  debug(" bar: "); debug(barCounter);
  debug(" firstbar: "); debug(firstBar); 
  debug(" middlebar: "); debug(middleBar); 
  debug(" lastbar: "); debugln(lastBar); 
}

// HOW TO: Select time signatures. 
// Using the 5 position switch we can pick the numerator of the time signature 4, 7, 8, 12, or 16. 
// By passing different divisions of the clock to the clock input we can select the denominator of the time signature. 
// Here are some example clock division inputs and some possible time signatures.
// | ---- Clock Division ---- | ------------- Time Signatures --------------|
// | 1ppqn (quarter notes)    | 4/4 select 4, 8/4 select 8, 7/4 select 7    |
// | 2ppqn (8ths)             | 4/4 select 8, 7/8 select 7, 12/8 select 12  |
// | 4ppqn (16ths)            | 4/4 select 16, 7/16 select 7, 3/4 select 12 |
//
// Changes to the barsPerPhrase and beatsPerBar switches will be picked up on the next phrase reset or when the reset button is pushed. 
void changeBeatsAndBars(){
  // Read phrase length, if HIGH set to 16 bars, if LOW set to 8 bars
  barsPerPhrase = digitalRead(barsPerPhrasePinNum) ? barsPerPhraseValues[1] : barsPerPhraseValues[0];
  debug("bars "); debug(barsPerPhrasePinNum); debug(" "); debug(digitalRead(barsPerPhrasePinNum)); debug(" "); debugln(barsPerPhrase);
  // Read 5 position switch to set beatsPerBar, 
  // each switch position is connected to it's own input pullup
  for (int i = 0; i < 5; i++) {
    int switchState = digitalRead(beatsPerBarPins[i]);
    debug("beatsPin "); debug(beatsPerBarPins[i]); debug(" "); debugln(switchState);
    if (switchState == HIGH) {
      beatsPerBar = beatsPerBarValues[i];
      break;
    }
    // If we looped through all the pins but none are reading high, set beatsPerBar to 4
    if (i == 4 && switchState == LOW){
      beatsPerBar = 4;
    }
  }
  debug("changeBeatsAndBars "); debug("beats "); debug(beatsPerBar); debug(" bars "); debugln(barsPerPhrase);
}

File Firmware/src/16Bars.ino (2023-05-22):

#include <Debounce.h>

// only pins 2 and 3 can interrupt
const byte clockSignalPin = 2;    // Connect your clock square wave signal here
const byte ledPin = LED_BUILTIN;  // Built-in LED
const byte resetButtonPin = 3;    // Reset button, push to reset counters to zero
const byte clockBarPin = 4;       // Outputs square wave every musical bar
const byte resetSignalPin = 5;    // Reset signal to reset seven segment LEDs
const byte triggerWidth = 50;     // milliseconds

// Debounce resetButton(resetButtonPin, 50, false); // Provides 50ms debounced button with methods #count and #resetCount
volatile byte beatCounter = 0;  // Counter for the clock pulses
volatile byte barCounter = 0;   // Counter for the musical bars
volatile byte barsPerPhrase = 16;
volatile byte beatsPerMeasure = 4;
volatile bool clockBarState = LOW;  // Led State, initially set to LOW
volatile bool resetOutputState = LOW;
volatile bool resetButtonState = LOW;     
volatile bool ledState = LOW;      
volatile bool clockState = LOW;
volatile bool lastClockState = LOW;
volatile bool lastResetButtonState = LOW;




void setup() {
  pinMode(clockSignalPin, INPUT);
  pinMode(resetButtonPin, INPUT);
  pinMode(clockBarPin, OUTPUT);
  pinMode(resetSignalPin, OUTPUT);
  pinMode(ledPin, OUTPUT);
  Serial.begin(9600);
  Serial.print("setup ");
}

void loop() {
  // TODO can we get the counters to count from 1 to 16 instead of 0 to 15? If barCounter == 0 send fast trigger to get leds to display 01 before next clock pulse?

    // TODO loop is reading the clock high see if clock changed? We were getting two loops within a short clock trigger need to detect rising edge
    // Alternatively set the loop speed to be longer than a clock, this doesn't handle gates, so we need to detect edges.
    // -- Loop 0
    // clock = LOW
    // lastClock set to LOW
    // NO OP clock not high
    // -- Loop 1
    // clock = HIGH
    // lastClock = LOW
    // Increment!
    // lastClock set to HIGH
    // --- Loop 2
    // clock = HIGH
    // lastClock = HIGH
    // NO OP, lastClock not low wait for clock to go low
    // -- Loop 3
    // clock = LOW
    // lastClock set to LOW
    // NO OP, clock not high
  lastClockState = clockState;
  lastResetButtonState = resetButtonState;
  clockState = digitalRead(clockSignalPin);
  if(clockState == LOW){
    lastClockState = LOW;
  }
  // bool resetButtonState = resetButton.read();
  if (resetButtonState && !lastResetButtonState) {
    Serial.println("----resetbutton---");
    barCounter = 0;
    beatCounter = 0;
    // digitalWrite(resetSignalPin, HIGH);
    resetOutputState = HIGH;
  }
  if (clockState == HIGH && lastClockState == LOW) {
    lastClockState = clockState;
    incrementCounters();
  }
}
// This function will be called whenever a rising edge is detected from the clock
void incrementCounters() {
  Serial.println("-------clock------");

  digitalWrite(clockBarPin, clockBarState);
  digitalWrite(resetSignalPin, resetOutputState);
  clockBarState = LOW;
  resetOutputState = LOW;

  beatCounter++;
  Serial.print("beat ");
  Serial.println(beatCounter);
  if (beatCounter >= beatsPerMeasure) {
    barCounter++;
    clockBarState = HIGH;
    // digitalWrite(clockBarPin, clockBarState);

    beatCounter = 0;
  }
  if (barCounter >= barsPerPhrase) {
    resetOutputState = HIGH;
    barCounter = 0;
    beatCounter = 0;
    // digitalWrite(resetSignalPin, resetOutputState);

    // TODO about to reset check state of switches for beatsPerMeasure and barsPerPhrase
  }

  Serial.print("bar ");
  Serial.println(barCounter);
  Serial.print("clockBar ");
  Serial.println(clockBarState);
  Serial.print("reset ");
  Serial.println(resetOutputState);
}


// TODO figure out different beat counters (4 or 8) based on switch
// TODO figure out time signatures 4/4, 8/4, 6/8, 7/8 -> how to pick numerator and denominator?
// IDEA: select numerator only with rotary encoder, 4,6,7,8,9,11,12,16 (8 position)
//       denominator depends on clock signal sent:
//       1ppqn (quarter notes): 4/4 select 4, 8/4 select 8, 11/4 select 11
//       2ppqn (8ths): 4/4 select 8, 7/8 select 7, 11/8 select 11
//       4ppqn (16ths); 4/4 select 16
//

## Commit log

2022-02-14 Let there be bars
    [16Bars.kicad_sch]
2022-02-17 LEDShield, Panel, Improve 16bars
    [16Bars.kicad_pcb, 16Bars.kicad_sch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]
2022-02-18 OshPark AfterDark Sheep Panel
    [LedPracticePanel-B_Cu.gbr, LedPracticePanel-B_Mask.gbr, LedPracticePanel-B_Paste.gbr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]
2022-02-23 Finished schematic and footprints
    [16Bars.kicad_pcb, 16Bars.kicad_sch]
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2022-02-23 Update PCB layout, shrunk silkscreen size
    [16Bars.kicad_pcb]
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2022-02-25 Updated Gerbers after width change
    [16Bars-B_Cu.gbr, 16Bars-B_Mask.gbr, 16Bars-B_Paste.gbr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]
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2022-03-03 Add measurements to 1U Blank
    [LedPracticePanel.kicad_pcb]
2022-12-15 Update LED Shield Practice
    Updated footprints for flush fitting resistors and reran traces. Build 2nd board from last years run, changed led resistors from 500 to 2k, 500 burned out leds with 12v.
    Board works but the clock led is lit and turns off when it receives a signal, the transistor is acting as a logic NOT, unsure how to debug, need time on the breadboard.
    [LEDShieldPractice.kicad_pcb, LEDShieldPractice.kicad_sch]
2022-12-15 Fix Transitor Logic Add LED Button Datasheet
    [16Bars.kicad_sch]
2022-12-19 Update LED Panel layout, added panel with mouse bites.
    [16Bars.kicad_pcb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]
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2023-01-04 Surface Mount Resistors and Caps, fix 7segment footprint
    [16Bars.kicad_pcb, 16Bars.kicad_sch]
2023-01-05 Tracks for 7Seg LEDs
    [16Bars.kicad_pcb]
2023-01-05 Fix transistor logic. TODO resistor values.
    [16Bars.kicad_sch, LEDShieldPractice.kicad_sch]
2023-01-05 Update PCB and Schematic Footprints
    Better 7Seg layout
    Update 7seg footprint
    [16Bars.kicad_pcb, 16Bars.kicad_sch]
2023-01-05 Add Thonk Low Profile LED Button Symbol
    [16Bars.kicad_sch]
2023-01-05 Add PowerLED. Add ThonkButton Symbol and Footprint
    [16Bars.kicad_pcb, 16Bars.kicad_sch]
2023-01-06 Complete Surface Mount Version
    Fix 16BarsReset Label by adding resistor
    Add TODOs for clock and bar division switches
    [16Bars-B_Cu.gbr, 16Bars-B_Mask.gbr, 16Bars-B_Paste.gbr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]
2023-01-09 SMD Transistors and LED
    Move fabrication files to Fabrication dir
    [16Bars-B_Cu.gbr, 16Bars-B_Mask.gbr, 16Bars-B_Paste.gbr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]
2023-01-09 Add LCSC Part Numbers
    [16Bars.kicad_sch]
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2023-01-11 Add 4MS Jack Symbol and Footprint
    [16Bars.kicad_pcb, 16Bars.kicad_sch]
2023-01-13 Add Power Regulation
    Described in this talk by Paul Schreiber of Synthesis Technology https://youtu.be/cBGyEBQnIws
    [16Bars.kicad_sch]
2023-01-24 Add component measurments from top left of board, start panel files.
    [16Bars.kicad_pcb, Panel.kicad_pcb]
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2023-01-28 Panel with artwork, holes, cutouts.
    Panel size was 8HP shrunk to 6HP.
    Logo is too big.
    [16Bars.kicad_pcb, 16Bars.kicad_sch, Panel.kicad_pcb]
2023-01-28 Fix Logo. Generate Gerbers
    [Panel-B_Cu.gbr, Panel-B_Mask.gbr, Panel-B_Paste.gbr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]
2023-01-28 Fix cutout, remove copper beneath
    TODO add M3 hole
    [Panel-B_Cu.gbr, Panel-B_Mask.gbr, Panel-B_Paste.gbr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]
2023-01-28 Don't override measurement values, it only changes the text.
    User4 layer in yellow is correct. Only affected jack and button holes and they were only off by a few 100's of a mm, SHOULD be ok?
    [Panel.kicad_pcb]
2023-01-29 Ground lamptest pin 14 on IC2
    [16Bars.kicad_sch]
2023-01-30 Use schotky diodes on input remove transistor for led blink
    Model in Falstad, added transistor to correctly invert reset logic.
    TODO figure out reset button. Should reset 4510 and 4033's, 16bar-reset should only reset 4033's.
    [16Bars.kicad_sch]
2023-01-31 [V2] Add Bar Counters and Switches
    Add switch for beats/bar
    Add switch for bars/phrase
    Add two 4510's for counting bars for configurable reset. Will support up to 128 bars/phrase, limited to 16 for now.
    [16Bars.kicad_sch]
2023-02-01 Add diode on reset switch output
    Falstad model showed the reset button voltage flowing back to the output pin(s) of the bar counter and not triggering the reset pins. Adding a diode helped current flow.
    [16Bars.kicad_sch]
2023-02-03 Updated Reset with Switch and 16 Bars
2023-02-04 Update Schematic From Falstad Model
    To reset the phrase two 4510's allow selecting phrase length of 4,8,16 bars.
    The clock divider 4510 now allows for 4/8 beats/bar.
    [16Bars.kicad_sch]
2023-02-07 Add transistors to normalize the clock signal
    [16Bars.kicad_sch]
2023-02-08 Normalize incoming clock, fix reset logic, logo
    Clock should now pickup very low voltage clocks. PGH Microvolt sends out 0.8v clock, not high enough to trigger CMOS logic.
    Flipped reset button so it's not connected directly to 12v with transistor. Use diode to OR button reset with PhraseReset clock signal.
    Mouser symbols need LibraryLoader installed from https://ms.componentsearchengine.com/pcb-libraries.php
    [16Bars.kicad_sch]
2023-02-10 Update footprints
    Source switches from Mouser, possibly look into samples from E-Switch
    [16Bars.kicad_sch]
2023-02-15 Change bars switch to SPDT
    Remove 4 bars option to make switch selection and footprint easier.
    [16Bars.kicad_sch]
2023-02-15 Trying to organize footprints and symbols
    Trying to avoid having to use LibraryLoader to get symbols and footprints on all machines. Would love to have symbols and footprints local to the project. Looks like I have to migrate older SamacSys .lib files to KiCAD sym files? Annoying.
2023-02-15 Use EG1249 switches in on-on config
    TODO: test on-on symbol configuration that I had to modify from the Mouser symbol/footprint.
    [16Bars.kicad_sch]
2023-02-16 Update PCB with V2 changes
    F.Cu SMD assembly will provide much more room for tracks instead of routing around ICs on B.Cu.
    [16Bars.kicad_pcb, 16Bars.kicad_sch]
2023-02-16 Seven Segment PCB Layout
    [16Bars.kicad_pcb]
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2023-02-28 Fix DRC errors
    [16Bars.kicad_pcb]
2023-02-28 Add measurements for panel
    [16Bars.kicad_pcb]
2023-02-28 Update panel measurement font size
    [16Bars.kicad_pcb]
2023-02-28 Add logo to main board. Add readme for how to get images on pcb
    [16Bars.kicad_pcb, Panel.kicad_pcb]
2023-03-02 Remove two mounting holes. Add full board measurements.
    [16Bars.kicad_sch, Panel.kicad_pcb]
2023-03-04 Square 5.3mm panel cutouts for switch travel
    Cutout doesn't need to be the size of the switch body :laughing:
    Switch travel in datasheet is 2mm middle to middle with a 2mm wide switch so it should travel 4mm. Measuring switch confirms 4mm travel. Give 0.75mm margin all around
    [Panel.kicad_pcb]
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2023-03-10 Add test points. Version layer test.
    Add test points on edge of pcb to test with alligator clips because that's what I have for my multimeter.
    The "16Bars Rev 2.0" I did in multiple layers to test look graphics in bare fr4 and bare copper
    [16Bars.kicad_pcb]
2023-03-10 Update panel design. Update logo on PCB
    [Panel.kicad_pcb]
2023-03-11 Fabrication Output for Rev 2.0
    [16Bars-B_Cu.gbr, 16Bars-B_Mask.gbr, 16Bars-B_Paste.gbr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]
2023-03-20 Remove PCB target in top left. Panel Design Updates
    [16Bars.kicad_pcb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]
2023-03-22 Rev2.0 Resistor layout is incorrect.
    [16Bars.kicad_pcb]
2023-03-22 DC offset might be the issue
    CLOCK_IN is in an always on state, need to scope the incoming signal to find out for sure.
    [16Bars.kicad_sch]
2023-03-27 Debugging incoming clock issues.
    [16Bars.kicad_pcb]
2023-03-30 Add 16Bar reset AND logic transistor to schematic
    [16Bars.kicad_sch]
2023-03-30 Revert to through hole resistors.
    Get resistor values correct for 16 bars reset AND gate.
    Add diode to Q2 reset button transistor.
    Fairly certain based on Falstad experiments JLCPCB placed PNP transistors instead of NPN, behavior of reset button in Falstad with PNP matches behavior observed on Rev2.0 PCB giving high reset signal by default and pulling to low when button pressed.
    [16Bars.kicad_pcb, 16Bars.kicad_sch]
2023-03-31 Track layout for TO-92 transistors. Needs DRC warning fixes.
    [16Bars.kicad_pcb]
2023-04-05 Cleanup fab layer, logo placement, and some routing
    [16Bars-bom.csv, 16Bars.kicad_pcb, JLC-16Bars-bom-2.1-jlc.csv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]
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2023-05-02 Attempt to fix reset logic
    Falstad model helped get resistor values dialed in so we're sending >9v when 16 count is reached between the two 4510 counters and 12v is sent from the reset button. Removed diodes to increase voltage as they were adding resistance.
    [16Bars.kicad_sch]
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2023-05-17 Layout SevenSegment Board. Nano Schematic
    [16Bars.kicad_sch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]
2023-05-30 Fix UberPin state. Getting reset logic closer.
    [16Bars.ino, UberPin.cpp]
2023-05-30 Figuring out reset button.
    Reset button release isn't getting picked up well so we're missing clock pulses.
    [16Bars.ino]
2023-05-31 Fixed reset logic.
    Reset now prevents clock from going through while held and keeps reset signal high.
    [16Bars.ino, UberPin.cpp]
2023-06-03 Add barsPerPhrasePin read on phrase reset.
    Redo bracket format.
    [16Bars.ino]
2023-06-05 Add five position switch to choose beatsPerBar on reset.
    [16Bars.ino]
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2023-06-05 Fix first, middle, last, bar pin names.
    [16Bars.ino]
2023-06-08 Add LED output pins. Hookup pins in schematic.
    [16Bars.kicad_sch]
2023-06-08 Add LCSC power regulator. Add SLB1570 5 position switch.
    [16Bars.kicad_sch]
2023-06-09 Add output jacks and leds.
    [16Bars.kicad_sch]
2023-06-10 Verified 1P5T Switch on Breadboard.
    [16Bars.kicad_sch]
2023-06-12 Remove AMS1117
    Arduino has one onboard!
    [16Bars.kicad_sch]
2023-06-12 Add labels for beatsPerBar
    [16Bars.kicad_sch]
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2023-06-12 Update PCB with Arduino. Add Miduino subproject.
    [16Bars.kicad_pcb, Miduino.kicad_pcb, Miduino.kicad_sch]
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2023-06-12 Reposition SevenSegment Header
    Still needs to move up 3.2mm to fit existing panel design.
    Might need to rebuild seven segment board. With current jack placement (kinda close to the Nano, we'll see how well it solders), we could put the 4033's back on the board but we'd need 2x7 pin headers to raise up just the TDSR0760's.
    Other option is to build a control board and a panel board. Panel board would house buttons, switches, leds, jacks, and seven segments. Control board would house Nano, 4033's, SMD's, Power and Cap. Control board would send 5v, GND, Jack I/O (1 In, 3 out), reset button, reset, seven segments x 2, switch output (1x + 5x = 6 pins) for a total of 28 pins lol.
    The other opti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
    [16Bars.kicad_pcb, SevenSegment.kicad_pcb]
2023-06-13 WIP Move Nano to bottom of board.
    [16Bars.kicad_pcb]
2023-06-13 Generate 3.0 Fabrication
    Added JLC bom python script.
    [16Bars-BOM.csv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]
2023-06-13 Add more fab files
    Resistors need to be updated on PCB
    [16Bars.kicad_pcb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]
2023-06-13 Update PCB with resistor changes
    [16Bars.kicad_pcb]
2023-07-01 Fix PCB layout issues and pins not working on Nano.
    [16Bars.kicad_pcb]
2023-07-06 SevenSegment PCB v1.0
    Push TDSR0706's together, move header pins, add more header pins for mechanical stability, make board less wide, rounded tracks, moved ICs to top of board for better clearance.
    [SevenSegment.kicad_pcb]
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2023-07-27 v3.1 Fabrication for PCB and Panel
    [16Bars-B_Cu.gbr, 16Bars-B_Mask.gbr, 16Bars-B_Paste.gbr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]
2023-09-13 Add startup led flashing to firmware.
    [SevenSegment.kicad_pcb]
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2024-05-14 Cleanup Comments. Add TODOs
    Finished the v3.2 build and it works! Noticed a few issues, zeros are not displaying probably from leaving the RBO and RBI (pins 3,4) on the 4033's floating, but need to test. I also left some comments about how I think we can make this count from 1 to 16, instead of from 0 (not showing) to 15. If I can fix the zeros displaying then maybe we don't have to deal with the extra pulse to skip "00" on the counters.
    [16Bars.kicad_sch, Miduino.kicad_pcb, Miduino.kicad_sch]
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2024-05-15 Add long press on reset at startup to enter test mode
    [16Bars.ino]
2024-05-16 Simplify entering test mode. Add auto-reset after 4 seconds.
    [16Bars.ino]
